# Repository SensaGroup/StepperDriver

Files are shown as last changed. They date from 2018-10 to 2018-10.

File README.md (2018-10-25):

# SENSA Smart Stepper Driver 
<p align="center"> 

</p>

### Main features
- on-board ATMEGA328/P
- A4988 module 
- CAN Bus - MCP25625
- Encoder and switch support

## What is the SENSA Smart Stepper Driver?
The SENSA Smart Stepper Driver is an add-on module for a stepper motor and houses all features needed to gain full control of your stepper motor.
Next to the on-board CAN Bus, the driver can also be controlled through USART or I2C.

### ATMEGA328/P
The ATMEGA328/P controls the whole board which is equipped with the Arduino platform.
It runs our [open-source code](), which can be easily modified for any project.

### A4988 module
We have chosen the easily accessible A4988 stepper driver module. It has all features that are needed and it is easy to control.

### MCP25625
The CAN Bus is a very robust communication protocol, which supports up to 1Mb/s speeds and it only requires 3 wires for it to work (CANH, CANL, GND).
The [MCP25625](http://ww1.microchip.com/downloads/en/DeviceDoc/20005282B.pdf) is a CAN controller with an integrated transceiver, meaning it doesn't take up much space.

### Encoder and switches
We have added a connector for an encoder, whose pins are connected to interrupt pins of the ATMEGA328/P. 
Two switches can be also added to the board via a connector, which can help you add control to your project. 

## Images
<p align="center"> 
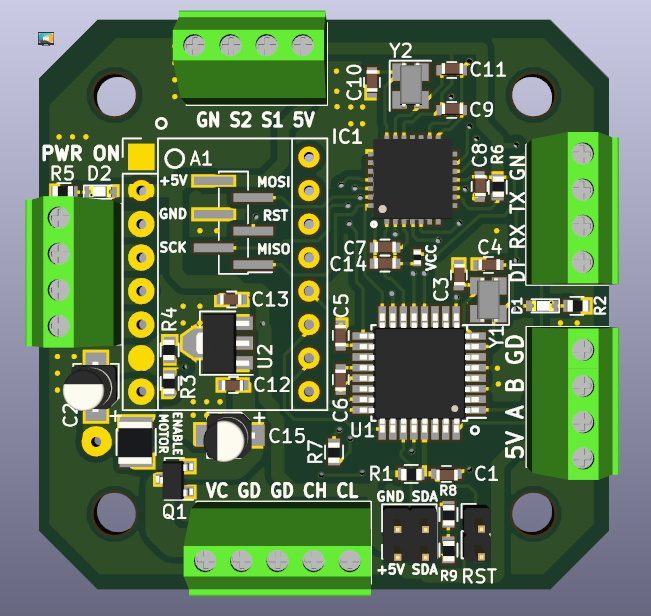
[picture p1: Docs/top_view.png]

</p>

## Sponsored by AISLER
### Develop and manufacture your own premium boards at [aisler.net](https://aisler.net/)

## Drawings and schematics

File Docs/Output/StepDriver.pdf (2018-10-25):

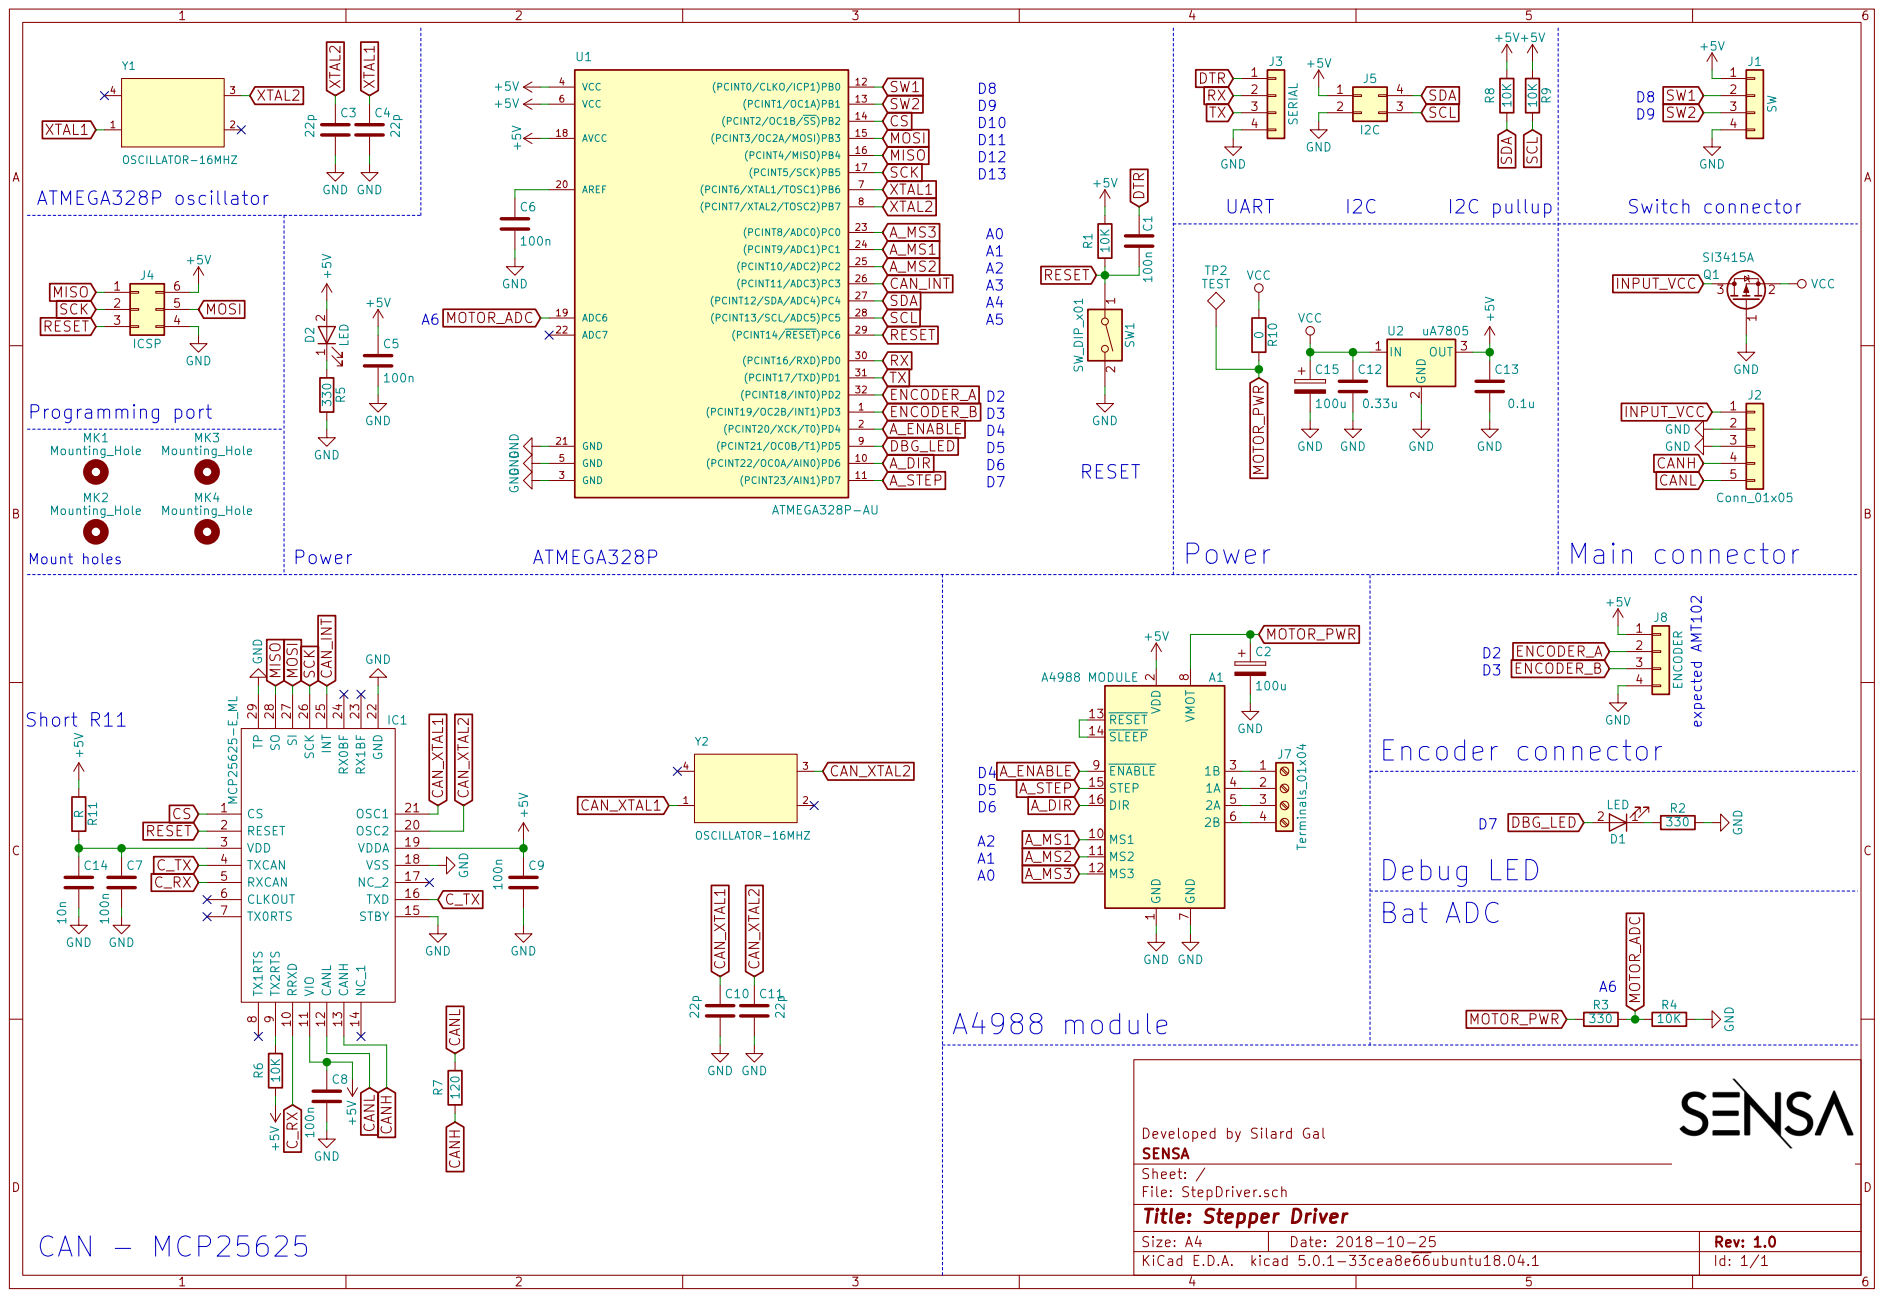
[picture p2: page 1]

1 MS1 10 MS2 11 MS3 12 RESET 13 SLEEP 14 STEP 15 DIR 16 VDD

9 RRXD 10 VIO 11 CANL 12 CANH 13 NC_1 14 OSC1 21 OSC2 20 VDDA 19 VSS 18 NC_2 17 TXD 16 STBY 15 TP 29 SO 28 SI 27 SCK 26 INT 25 RX0BF 24 RX1BF 23 GND 22 IC1 MCP25625-E_ML GND

File: StepDriver.sch Sheet: / SENSA

Id: 1/1 Title: Stepper Driver

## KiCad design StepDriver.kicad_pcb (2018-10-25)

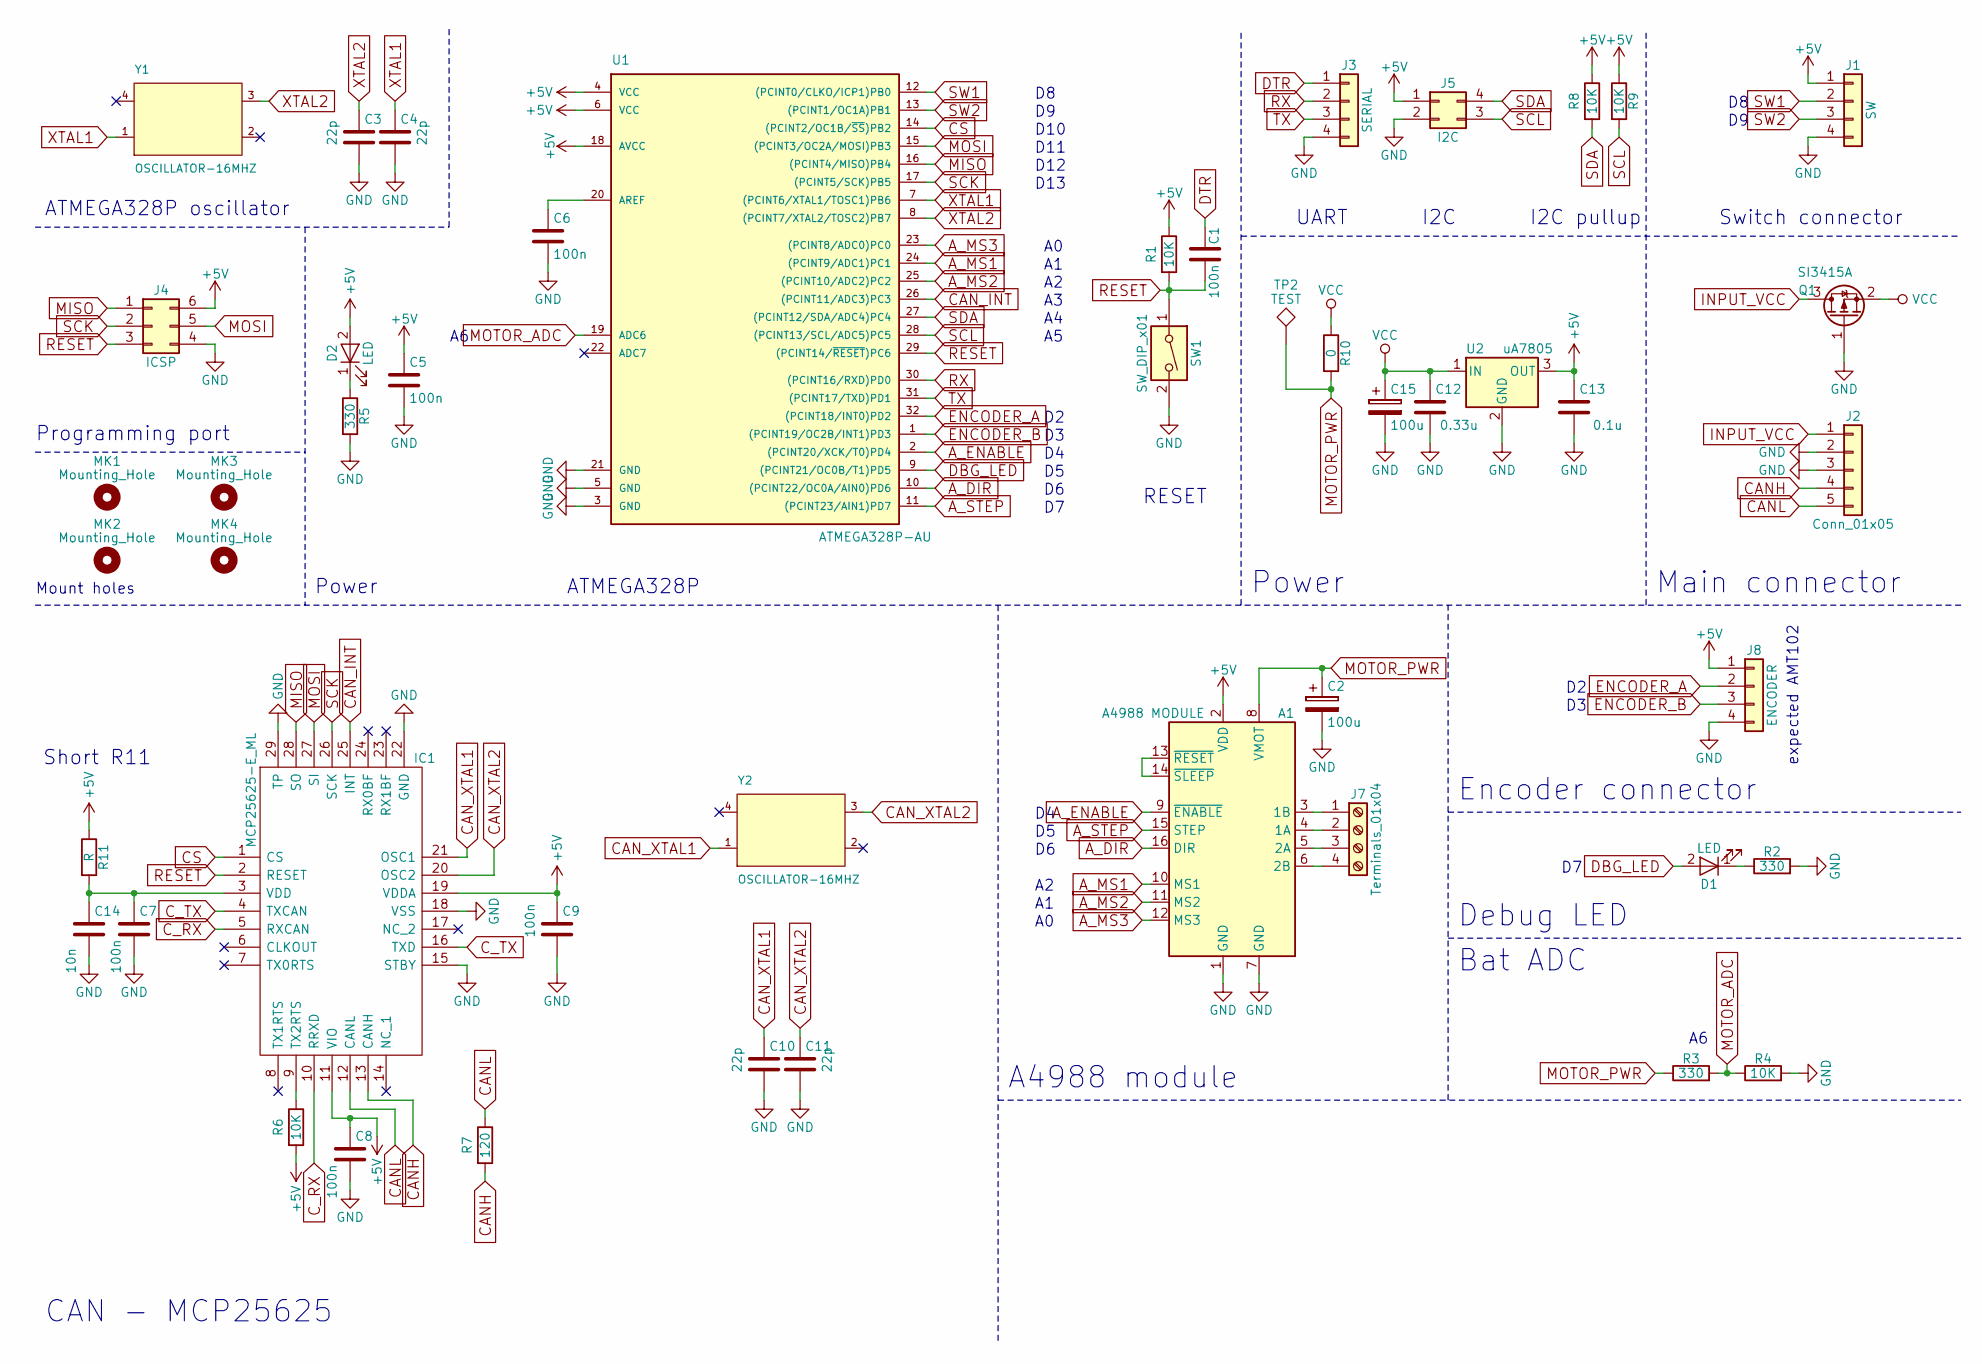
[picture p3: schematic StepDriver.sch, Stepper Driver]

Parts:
A1: A4988 MODULE; Pololu_Breakout-16_15.2x20.3mm
C1, C5, C6, C7, C8, C9: 100n; C_0603
C2, C15: 100u; CP_Elec_3x5.3
C3, C4, C10, C11: 22p; C_0603
C12: 0.33u; C_0603
C13: 0.1u; C_0603
C14: 10n; C_0603
D1, D2: LED; LED_0603
IC1: MCP25625-E_ML; QFN65P600X600X100-29N-D; Manufacturer_Part_Number MCP25625-E/ML
J1: SW; TerminalBlock_Phoenix_MPT-2.54mm_4pol
J2: Conn_01x05; TerminalBlock_Phoenix_MPT-2.54mm_5pol
J3: SERIAL; TerminalBlock_Phoenix_MPT-2.54mm_4pol
J4: ICSP; Pin_Header_Straight_1x06_Pitch1.27mm_SMD_Pin1Left
J5: I2C; Pin_Header_Straight_2x02_Pitch2.00mm
J7: Terminals_01x04; TerminalBlock_Phoenix_MPT-2.54mm_4pol
J8: ENCODER; TerminalBlock_Phoenix_MPT-2.54mm_4pol
MK1, MK2, MK3, MK4: Mounting_Hole; MountingHole_3.2mm_M3
Q1: SI3415A; SOT-23
R1, R4, R6, R8, R9: 10K; R_0603
R2, R3, R5: 330; R_0603
R7: 120; R_0603
R10: 0; R_1210
R11: R; R_0402_NoSilk
SW1: SW_DIP_x01; Pin_Header_Straight_1x02_Pitch2.00mm
TP2: TEST; SolderWirePad_single_0-8mmDrill
U1: ATMEGA328P-AU; TQFP-32_7x7mm_Pitch0.8mm
U2: uA7805; SOT-89-3
Y1, Y2: OSCILLATOR-16MHZ; Oscillator_SMD_Abracon_ASE-4pin_3.2x2.5mm

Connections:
+5V: A1.2 (VDD), C5.1, C8.1, C9.1, C13.1, D2.2 (A), IC1.11 (VIO), IC1.19 (VDDA), J1.1, J4.6, J5.1, J8.1, R1.1, R6.2, R8.1, R9.1, R11.1, U1.4 (VCC), U1.6 (VCC), U1.18 (AVCC), U2.3 (OUT)
A_DIR: A1.16 (DIR), U1.10 ((PCINT22/OC0A/AIN0)PD6)
A_ENABLE: A1.9 (~ENABLE), U1.2 ((PCINT20/XCK/T0)PD4)
A_MS1: A1.10 (MS1), U1.24 ((PCINT9/ADC1)PC1)
A_MS2: A1.11 (MS2), U1.25 ((PCINT10/ADC2)PC2)
A_MS3: A1.12 (MS3), U1.23 ((PCINT8/ADC0)PC0)
A_STEP: A1.15 (STEP), U1.11 ((PCINT23/AIN1)PD7)
CANH: IC1.13 (CANH), J2.4, R7.2
CANL: IC1.12 (CANL), J2.5, R7.1
CAN_INT: IC1.25 (INT), U1.26 ((PCINT11/ADC3)PC3)
CAN_XTAL1: C10.1, IC1.21 (OSC1), Y2.1 (EN)
CAN_XTAL2: C11.1, IC1.20 (OSC2), Y2.3 (OUT)
CS: IC1.1 (CS), U1.14 ((PCINT2/OC1B/~SS~)PB2)
C_RX: IC1.5 (RXCAN), IC1.10 (RRXD)
C_TX: IC1.4 (TXCAN), IC1.16 (TXD)
DBG_LED: D1.2 (A), U1.9 ((PCINT21/OC0B/T1)PD5)
DTR: C1.1, J3.1
ENCODER_A: J8.2, U1.32 ((PCINT18/INT0)PD2)
ENCODER_B: J8.3, U1.1 ((PCINT19/OC2B/INT1)PD3)
GND: A1.1 (GND), A1.7 (GND), C2.2, C3.2, C4.2, C5.2, C6.2, C7.2, C8.2, C9.2, C10.2, C11.2, C12.2, C13.2, C14.2, C15.2, IC1.15 (STBY), IC1.18 (VSS), IC1.22 (GND), IC1.29 (TP), J1.4, J2.2, J2.3, J3.4, J4.4, J5.2, J8.4, Q1.1 (G), R2.2, R4.2, R5.2, SW1.2, U1.3 (GND), U1.5 (GND), U1.21 (GND), U2.2 (GND); also elsewhere on the board
INPUT_VCC: J2.1, Q1.3 (D)
MISO: IC1.28 (SO), J4.1, U1.16 ((PCINT4/MISO)PB4)
MOSI: IC1.27 (SI), J4.5, U1.15 ((PCINT3/OC2A/MOSI)PB3)
MOTOR_ADC: R3.2, R4.1, U1.19 (ADC6)
MOTOR_PWR: A1.8 (VMOT), C2.1, R3.1, R10.2, TP2.1
unnamed: A1.3 (1B), J7.1
unnamed: A1.4 (1A), J7.2
unnamed: A1.5 (2A), J7.3
unnamed: A1.6 (2B), J7.4
unnamed: A1.13 (~RESET), A1.14 (~SLEEP)
unnamed: C6.1, U1.20 (AREF)
unnamed: C7.1, C14.1, IC1.3 (VDD), R11.2
unnamed: D1.1 (K), R2.1
unnamed: D2.1 (K), R5.1
unnamed: IC1.9 (TX2RTS), R6.1
RESET: C1.2, IC1.2 (RESET), J4.3, R1.2, SW1.1, U1.29 ((PCINT14/~RESET~)PC6); also elsewhere on the board
RX: J3.2, U1.30 ((PCINT16/RXD)PD0)
SCK: IC1.26 (SCK), J4.2, U1.17 ((PCINT5/SCK)PB5)
SCL: J5.3, R9.2, U1.28 ((PCINT13/SCL/ADC5)PC5)
SDA: J5.4, R8.2, U1.27 ((PCINT12/SDA/ADC4)PC4)
SW1: J1.2, U1.12 ((PCINT0/CLKO/ICP1)PB0)
SW2: J1.3, U1.13 ((PCINT1/OC1A)PB1)
TX: J3.3, U1.31 ((PCINT17/TXD)PD1)
VCC: C12.1, C15.1, Q1.2 (S), R10.1, U2.1 (IN)
XTAL1: C4.1, U1.7 ((PCINT6/XTAL1/TOSC1)PB6), Y1.1 (EN)
XTAL2: C3.1, U1.8 ((PCINT7/XTAL2/TOSC2)PB7), Y1.3 (OUT)

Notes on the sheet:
expected AMT102
D10
D11
D12
D13
Mount holes
ATMEGA328P oscillator
ATMEGA328P
Power
UART
I2C
I2C pullup
Switch connector
Main connector
Power
A4988 module
Bat ADC
Debug LED
Encoder connector
CAN - MCP25625
Programming port
RESET
Short R11

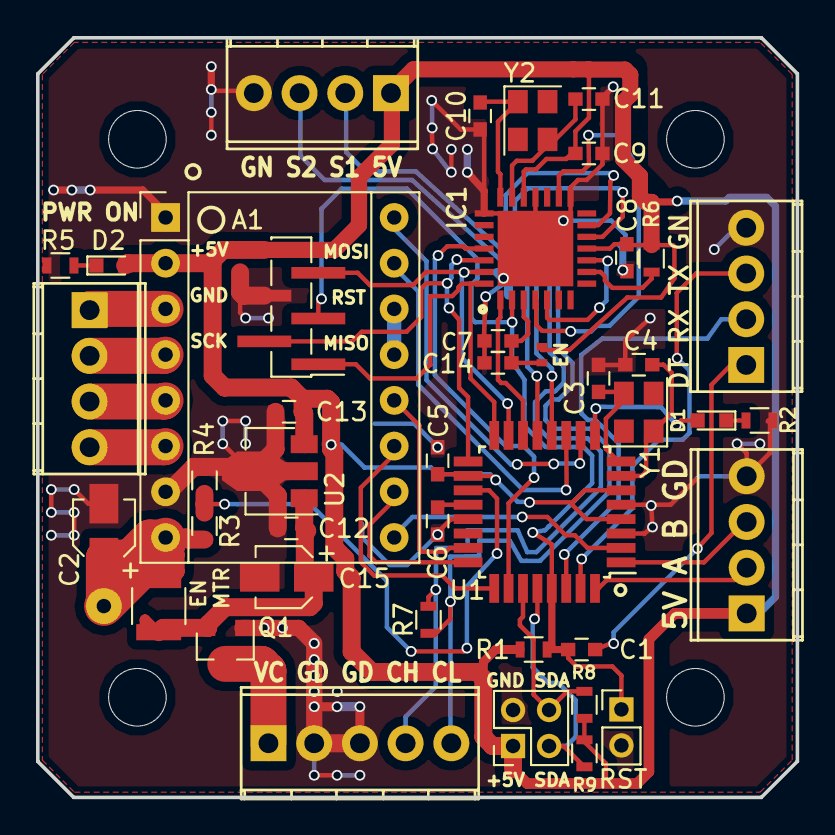
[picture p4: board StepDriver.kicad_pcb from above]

Board: 2 copper layers, 42.2 x 42.2 mm, 48 parts (0 on the bottom side), 46 nets.

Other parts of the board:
RST: SW_DIP_x01; Pin_Header_Straight_1x02_Pitch2.00mm

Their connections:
GND: RST.2; also elsewhere on the board
RESET: RST.1; also elsewhere on the board

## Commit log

2018-10-14 All files
    [StepDriver.kicad_pcb, StepDriver.sch]
2018-10-25 Small changes, added step and refined schematic and images
    [StepDriver-2018-10-25-13-53-13.sch, StepDriver.kicad_pcb, StepDriver.sch]
2018-10-25 change board
